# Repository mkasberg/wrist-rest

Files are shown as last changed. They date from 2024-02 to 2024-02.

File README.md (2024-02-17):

# Keyboard Wrist Rest

A 3D-printable keyboard wrist rest in [OpenSCAD](https://openscad.org/downloads.html).

**[Keyboard Wrist Rest (Chevron) on Printables](https://www.printables.com/model/764510-keyboard-wrist-rest-chevron)**

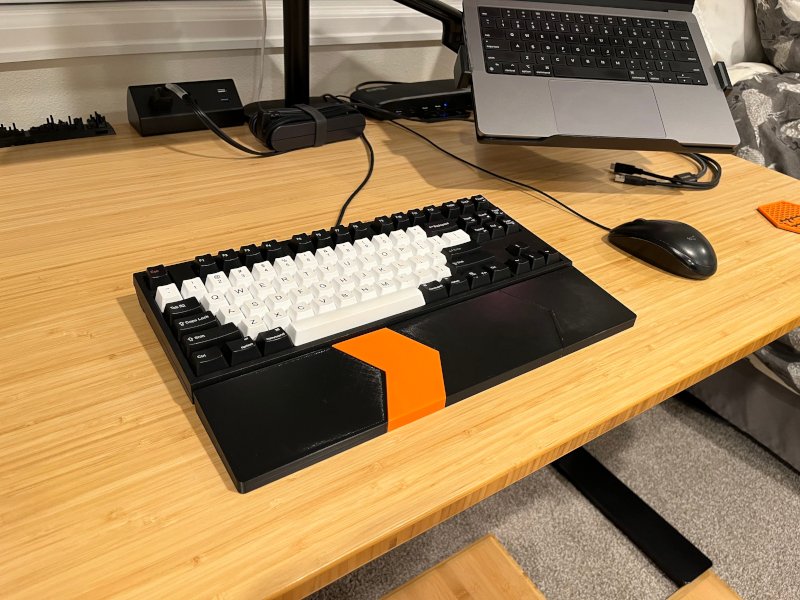
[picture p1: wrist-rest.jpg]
3D printed wrist rest


A wrist rest that looks great next to your mechanical keyboard! Add some personality to your battle station by printing this in your favorite colors!

The wrist rest is broken up into multiple sections with a chevron design. This allows you to print interesting color combinations and also means you can print this wrist rest on smaller printers – I printed mine on a MINI!

It's perfectly sized for my 87 key WASD, and should fit many othermechanical (or normal) keyboards well. I've also provided STL files with different length for 61 keys and 104 keys. If this doesn't meet your needs, you can customize the parameters in OpenSCAD.

## Printing Tips

 - After importing the STL, use “Split to objects” so you can rearrange the pieces for your printer. For small printers delete the pieces that don't fit (and print them separately).
 - I recommend printing the model upside down – this will produce a comfortable top side (with the smooth texture of your print sheet) and a rougher/grippier bottom.
 - I used 0.2mm layer height (structural) settings in Prusa Slicer. Larger layer heights make the top of the print (the bottom of the wrist rest if you print upside down) rougher because of the slope.
 - Use supports under the alignment pins. Supports aren't needed in the holes.
 - 10-15% infill is sufficient.
 - Glue the pieces together when you're done printing.

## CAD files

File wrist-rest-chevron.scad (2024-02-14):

/*
A (Parametric) Keyboard Wrist Rest
with a Chevron Design
by Mike Kasberg

Default size optimized for WASD tenkeyless keyboards.

Tip: Print upside down for a smooth top and slightly rough/grippy bottom!
*/

// COMMON LENGTHS:
// 61-key      290
// Tenkeyless  360
// Full        440


// The height of the front of the wrist rest.
front_height =10;
// The height of the back of the wrist rest. Typically slightly larger than front height.
back_height = 18;
// The depth (front to back) of the wrist rest.
depth = 80;
// The length of the wrist rest in the longest direction.
length = 360;

// Radius of the rounded front corners.
corner_radius = 4;

// How far from the left to inset the design.
design_inset = 125;

// Extra cut on the right sie for smaller printers. 0 for none.
extra_cut_inset = 290;

// Depth tolerance for connecting pins.
pin_depth_tolerance = 4;

// Size tolerance for connecting pins.
pin_size_tolerance = 0.4;

module base_shape() {
  translate([length, depth, 0]) rotate([0, 0, -90]) rotate([90, 0, 0]) {
    linear_extrude(height = length) {
      polygon([[0, 0], [depth, 0], [depth, front_height], [0, back_height]]);
    }
  }
}

module corner_cut() {
  difference() {
    translate([0, 0, (back_height / 2)])
      cube([2 * corner_radius, 2 * corner_radius, back_height + 2], center = true);
    translate([corner_radius, corner_radius, -1.1])
      cylinder(h = back_height + 2.2, r = corner_radius, $fn=64);
  }
}

module wrist_rest() {
  difference() {
    base_shape();
    corner_cut();
    translate([length, 0, 0]) rotate([0, 0, 90]) corner_cut();
  }
}

module pin(is_male=true) {
  if (is_male) {
    rotate([45, 0, 0]) cube([20, 4, 4]);
  } else {
    rotate([45, 0, 0])
      translate([0, -pin_size_tolerance / 2, -pin_size_tolerance / 2])
      cube([20, 4 + pin_size_tolerance, 4 + pin_size_tolerance]);
  }
}

module cutter(is_male = true) {
  translate([-300, depth/2, -1]) cylinder(h=back_height + 2, r = 300, $fn=6);
  
  tolerance = is_male ? 0 : pin_depth_tolerance;
  translate([-10 - depth/6 + tolerance, depth / 3, (front_height - 4/cos(45))/2])
    pin(is_male);
 
  translate([-10 - depth/6 + tolerance, 2 * depth / 3, (front_height - 4/cos(45))/2])
    pin(is_male);
}


intersection() {
  wrist_rest();
  translate([design_inset, 0, 0]) cutter(true);
}

translate([10, 0, 0]) intersection() {
  difference() {
    wrist_rest();
    translate([design_inset, 0, 0]) cutter(false);
  }
  translate([design_inset + 0.6 * depth, 0, 0]) cutter(true);
}

if (extra_cut_inset > 0) {
  translate([20, 0, 0]) intersection() {
    difference() {
      wrist_rest();
      translate([design_inset + 0.6 * depth, 0, 0]) cutter(false);
    }
    translate([extra_cut_inset, 0, 0]) cutter(true);
  }

  translate([30, 0, 0]) difference() {
    wrist_rest();
    translate([extra_cut_inset, 0, 0]) cutter(false);
  }
} else {
  translate([20, 0, 0]) difference() {
    wrist_rest();
    translate([design_inset + 0.6 * depth, 0, 0]) cutter(false);
  }
}

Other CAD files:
wrist-rest.scad

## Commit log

2024-02-14 Change to a single chevron
    [wrist-rest-chevron.scad]
2024-02-14 Handle no extra cut
    [wrist-rest-chevron.scad]
